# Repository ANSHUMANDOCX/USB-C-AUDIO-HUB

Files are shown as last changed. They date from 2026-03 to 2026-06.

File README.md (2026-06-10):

# USB C AUDIO + USB HUB

## About
This is a USB C HUB along with a Audio Out/In port. This design uses PCM2912A along with SL2.1A 

- It has 3 downstream USB-C ports and 1 USB-C input so we can connect any desired length of cable we want to use with it
- TRRS audio jack for headphones with integrated microphone along with a mute/unmute switch built into the hub 
## Usage guide
- using it is as simple as it can be you just need to plug into the single usb C on the side and connected it to your device there are no driver needed 
- It doesnt need any firmware flashing 
- Its compatible with windows and linux 
## Assembly guide
All you need to do is place the PCB at the base plate align the holes and place the Body on top of it and screw the two parts using M2.5x6 or M2.5x8 countersunk screws.
## Parts used 
- TRRS Audio port
- USB C ports 
- PCM2912A
- SL2.1A
## Features
- USB 2.0 Full-Speed audio interface
- Stereo DAC output for headphones
- Microphone input with bias supply
- Integrated USB hub for multiple downstream devices
## PCB SCHEMATIC AND CAD





## Build 
WhatsApp Image 2026-06-11 at 12 53 12 AM
WhatsApp Image 2026-06-11 at 12 53 12 AM (1)
WhatsApp Image 2026-06-11 at 12 53 12 AM (2)
WhatsApp Image 2026-06-11 at 12 53 10 AM (1)
WhatsApp Image 2026-06-11 at 12 53 11 AM
https://drive.google.com/file/d/1LVbVrCVM0A2IdHVQDUf04vvttPNs0SB3/view?usp=sharing

## BOM
| SL NO | DESCRIPTION | SUPPLIER | PRICE |
|---|---|---|---|
| 1 | [LCSC BOM items](https://github.com/ANSHUMANDOCX/USB-C-AUDIO-HUB/blob/main/PCB/BOM.csv) | LCSC | $22 |
| 2 | PCB and Stencil | JLCPCB | $16 |
| 3 | Screws and Heatset Inserts | Only Screws | $2 |
|4| [Solder Paste](https://www.flipkart.com/babatools-rl-403-solder-paste-10cc-1-w-simple/p/itm13022305a7dd0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,1,G,11214002,g,search,,784823478926,,,,c,,,,,,,&&cmpid=content_23274603117_gmc_pla&gad_campaignid=23274603117) | Flipkart| 4$|
|  | **TOTAL** |  | **$44** |

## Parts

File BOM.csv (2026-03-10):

Index | LCSC# | MPN | Manufacturer | Package | Customer # | Description | RoHS | Quantity | MOQ | Multiple | Unit Price($) | Extended Price($) | Product Link
1 | C60474 | CC0402KRX7R7BB104 | YAGEO | 0402 |  | 100nF ±10% 16V Ceramic Capacitor X7R 0402 | yes | 100 | 100 | 100 | 0.0010 | 0.10 | https://www.lcsc.com/product-detail/C60474.html
2 | C192893 | SL2.1A | CoreChips | SOP-16 |  | 4 USB 2.0 Hub SOP-16 Interface Controllers RoHS | yes | 5 | 5 | 5 | 0.2329 | 1.16 | https://www.lcsc.com/product-detail/C192893.html
3 | C475497 | PCM2912APJTR | TI | TQFP-32(7x7) |  | Encoder/decoder USB TQFP-32(7x7) CODECS RoHS | yes | 2 | 1 | 1 | 4.6145 | 9.23 | https://www.lcsc.com/product-detail/C475497.html
4 | C318866 | XKB5858-Z-80 | XKB Connection | DIP-6,5.8x5.8mm |  | Latching DPDT Through Hole Square Button 1.6N 30V DIP-6,5.8x5.8mm Pushbutton Switches RoHS | yes | 5 | 5 | 5 | 0.1721 | 0.86 | https://www.lcsc.com/product-detail/C318866.html
5 | C60490 | RC0402FR-0710KL | YAGEO | 0402 |  | 62.5mW 10kΩ 50V Thick Film Resistor ±100ppm/℃ ±1% 0402 Chip Resistor - Surface Mount RoHS | yes | 100 | 100 | 100 | 0.0008 | 0.08 | https://www.lcsc.com/product-detail/C60490.html
6 | C114759 | RC0402FR-071K5L | YAGEO | 0402 |  | 62.5mW 1.5kΩ 50V Thick Film Resistor ±100ppm/℃ ±1% 0402 Chip Resistor - Surface Mount RoHS | yes | 100 | 100 | 100 | 0.0008 | 0.08 | https://www.lcsc.com/product-detail/C114759.html
7 | C17477 | 0805W8F0000T5E | UNI-ROYAL | 0805 |  | 0Ω ±1% 125mW 0805 Thick Film Resistor | yes | 100 | 100 | 100 | 0.0021 | 0.21 | https://www.lcsc.com/product-detail/C17477.html
8 | C105872 | RC0402FR-075K1L | YAGEO | 0402 |  | 5.1kΩ 62.5mW 50V Thick Film Resistor ±100ppm/℃ ±1% 0402 Chip Resistor - Surface Mount RoHS | yes | 100 | 100 | 100 | 0.0009 | 0.09 | https://www.lcsc.com/product-detail/C105872.html
9 | C137933 | RC0402FR-07820RL | YAGEO | 0402 |  | 820Ω 62.5mW 50V Thick Film Resistor ±100ppm/℃ ±1% 0402 Chip Resistor - Surface Mount RoHS | yes | 100 | 100 | 100 | 0.0008 | 0.08 | https://www.lcsc.com/product-detail/C137933.html
10 | C114765 | RC0402FR-0722RL | YAGEO | 0402 |  | 22Ω 62.5mW 50V Thick Film Resistor ±100ppm/℃ ±1% 0402 Chip Resistor - Surface Mount RoHS | yes | 100 | 100 | 100 | 0.0008 | 0.08 | https://www.lcsc.com/product-detail/C114765.html
11 | C16772 | CL05B224KO5NNNC | Samsung Electro-Mechanics | 0402 |  | 220nF ±10% 16V Ceramic Capacitor X7R 0402 | yes | 50 | 50 | 50 | 0.0041 | 0.21 | https://www.lcsc.com/product-detail/C16772.html
12 | C106200 | CC0402JRNPO9BN101 | YAGEO | 0402 |  | 100pF ±5% 50V Ceramic Capacitor NP0 0402 | yes | 100 | 100 | 100 | 0.0012 | 0.12 | https://www.lcsc.com/product-detail/C106200.html
13 | C107000 | CC0402JRNPO9BN200 | YAGEO | 0402 |  | 20pF ±5% 50V Ceramic Capacitor NP0 0402 | yes | 100 | 100 | 100 | 0.0011 | 0.11 | https://www.lcsc.com/product-detail/C107000.html
14 | C7196 | TAJB107M010RNJ | Kyocera AVX | CASE-B-3528-21(mm) |  | 100uF ±20% 10V Tantalum Capacitors 1.4Ω@100kHz CASE-B-3528-21(mm) | yes | 3 | 1 | 1 | 0.3492 | 1.05 | https://www.lcsc.com/product-detail/C7196.html
15 | C7469983 | FVH010ADA101M0554 | FOSAN | 5x5.4 |  | 100uF ±20% 10V Aluminum Electrolytic Capacitors | yes | 20 | 20 | 20 | 0.0341 | 0.68 | https://www.lcsc.com/product-detail/C7469983.html
16 | C315248 | CL05A106MP5NUNC | Samsung Electro-Mechanics | 0402 |  | 10uF ±20% 10V Ceramic Capacitor X5R 0402 | yes | 20 | 20 | 20 | 0.0091 | 0.18 | https://www.lcsc.com/product-detail/C315248.html
17 | C51412 | CL10A335KP8NNNC | Samsung Electro-Mechanics | 0603 |  | 3.3uF ±10% 10V Ceramic Capacitor X5R 0603 | yes | 10 | 10 | 10 | 0.0193 | 0.19 | https://www.lcsc.com/product-detail/C51412.html
18 | C14445 | CL05A105KP5NNNC | Samsung Electro-Mechanics | 0402 |  | 1uF ±10% 10V Ceramic Capacitor X5R 0402 | yes | 100 | 100 | 100 | 0.0021 | 0.21 | https://www.lcsc.com/product-detail/C14445.html
19 | C18185602 | PJ-320A-4P DIP | SHOU HAN | Through Hole |  | 3.5mm Headphone Jack 0.5A 30V Through Hole | yes | 10 | 10 | 10 | 0.0518 | 0.52 | https://www.lcsc.com/product-detail/C18185602.html
20 | C7528811 | H6OEL89CSC-SUGYLC-6M | YXC Crystal Oscillators | HC-49S-SMD |  | Crystal 6MHz ±20ppm 20pF HC-49S-SMD | yes | 5 | 5 | 5 | 0.0850 | 0.43 | https://www.lcsc.com/product-detail/C7528811.html
21 | C22400405 | FTC252012S1R0MBCD | cjiang | 1008 |  | 5.2A 1uH 16mΩ 6.5A ±20% 1008 Fixed Inductors RoHS | yes | 5 | 5 | 5 | 0.1119 | 0.56 | https://www.lcsc.com/product-detail/C22400405.html
22 | C105621 | CC0603JRNPO9BN200 | YAGEO | 0603 |  | 20pF ±5% 50V Ceramic Capacitor NP0 0603 | yes | 100 | 100 | 100 | 0.0027 | 0.27 | https://www.lcsc.com/product-detail/C105621.html
23 | C970683 | RVT1A101M0505 100UF 10V | DMBJ | SMD,D5xL5.4mm |  | 100uF ±20% 10V Aluminum Electrolytic Capacitors 2800hrs@105℃ | yes | 20 | 20 | 20 | 0.0354 | 0.71 | https://www.lcsc.com/product-detail/C970683.html
24 | C2927038 | USB-TYPE-C-018 | DEALON | SMD |  | USB-C (USB TYPE-C) Receptacle Connector 16 Position Surface Mount, Right Angle | yes | 10 | 10 | 10 | 0.0522 | 0.52 | https://www.lcsc.com/product-detail/C2927038.html
25 | C76960 | GRM1555C1H220JA01D | muRata | 0402 |  | 22pF ±5% 50V Ceramic Capacitor C0G 0402 | yes | 100 | 100 | 100 | 0.0026 | 0.26 | https://www.lcsc.com/product-detail/C76960.html

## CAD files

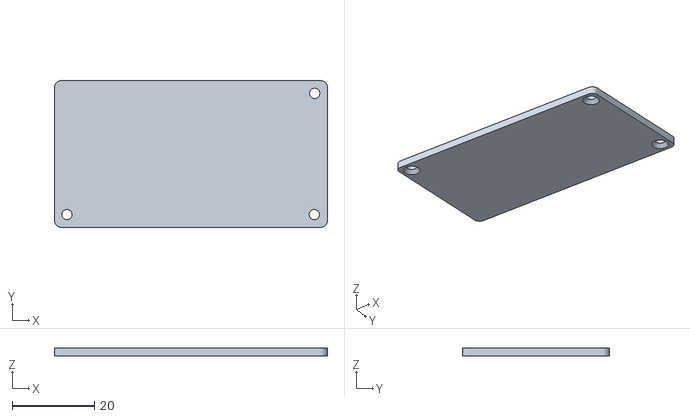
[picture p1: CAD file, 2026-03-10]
CAD/Base.stl
66.2 x 35.6 x 2.00

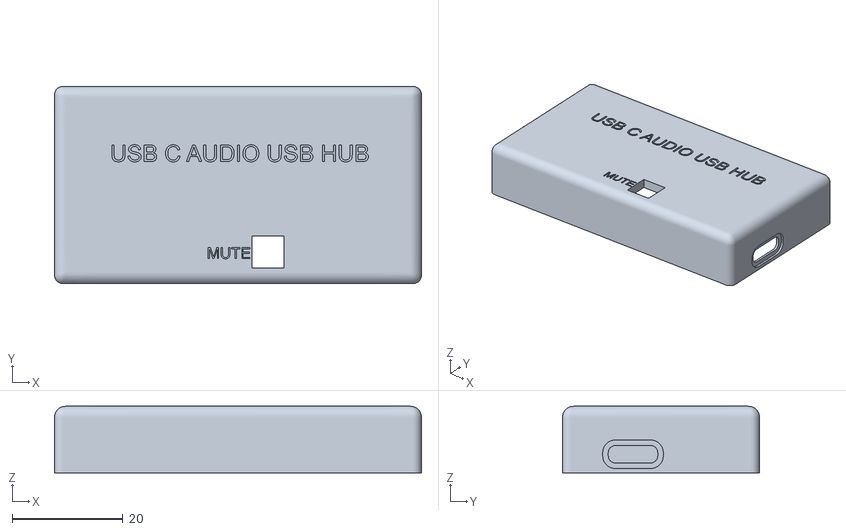
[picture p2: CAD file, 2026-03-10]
CAD/body.stl
66.2 x 35.6 x 12.0

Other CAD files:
CAD/Base.f3z
CAD/body.f3z

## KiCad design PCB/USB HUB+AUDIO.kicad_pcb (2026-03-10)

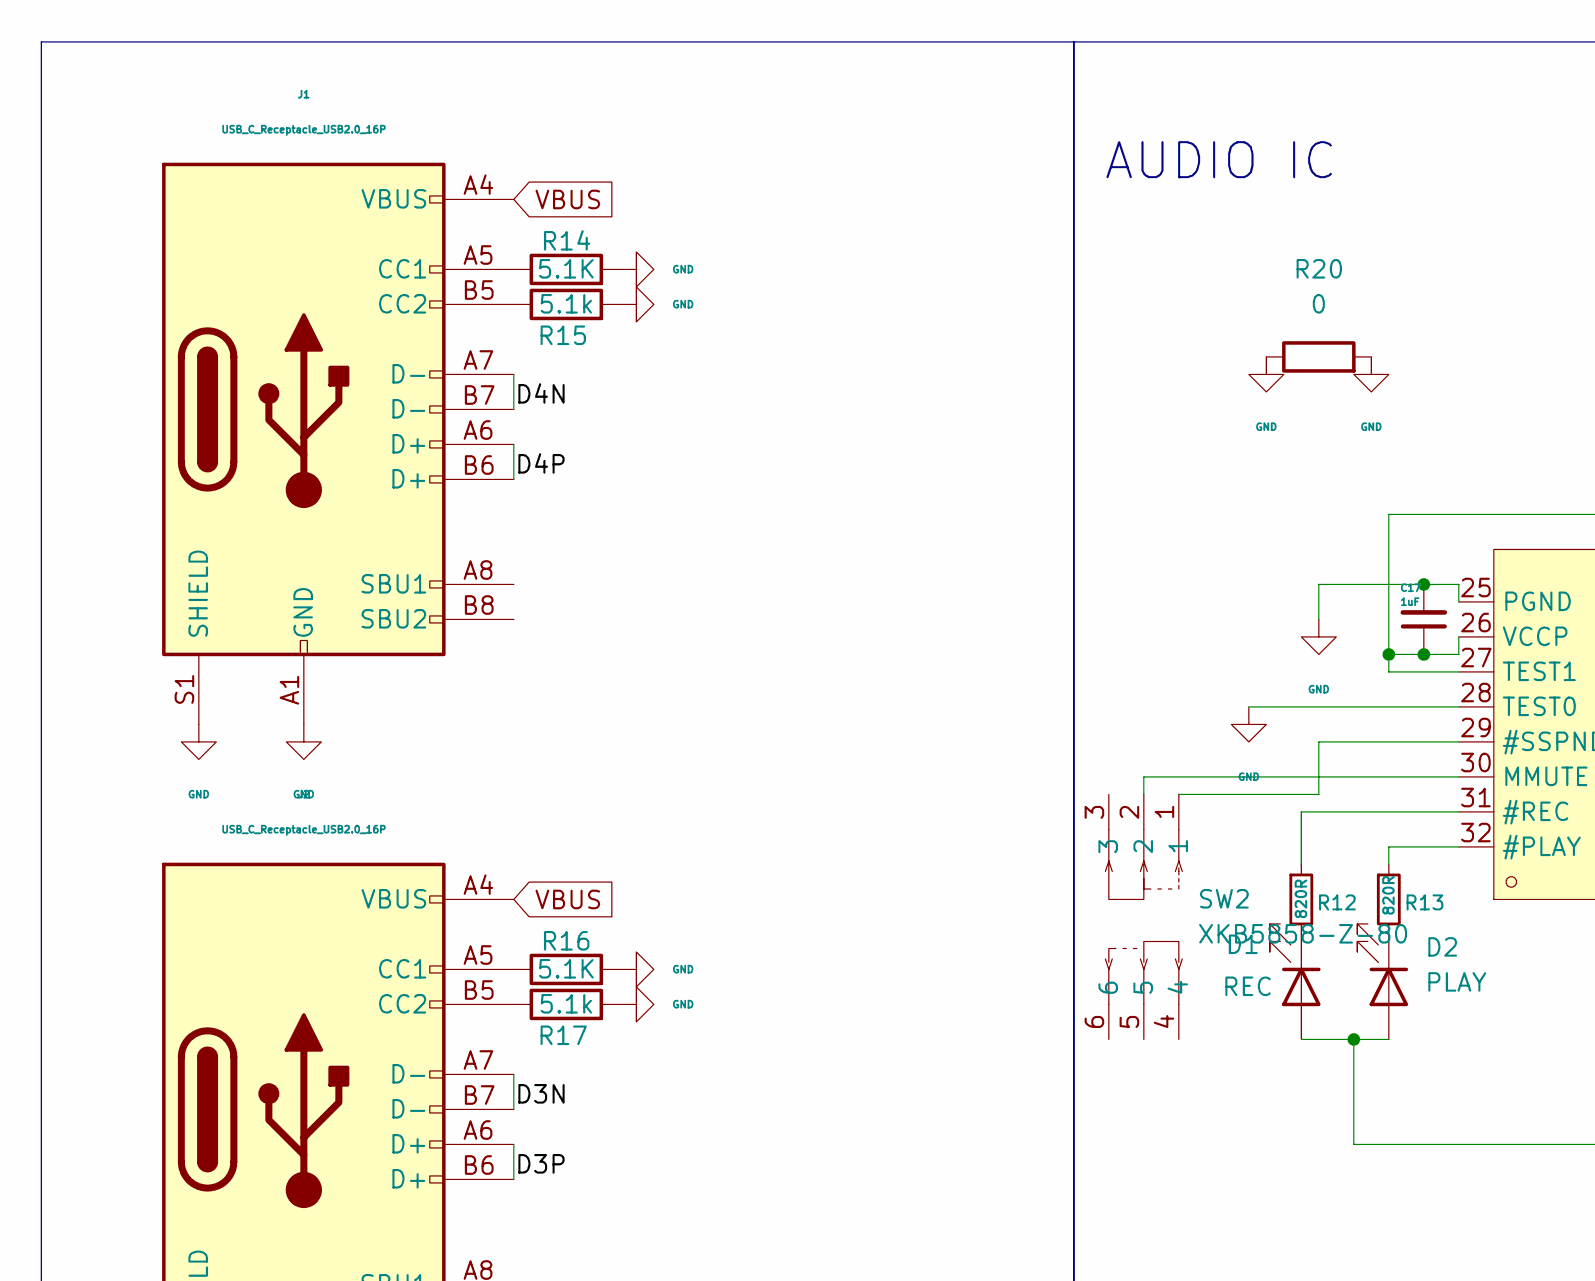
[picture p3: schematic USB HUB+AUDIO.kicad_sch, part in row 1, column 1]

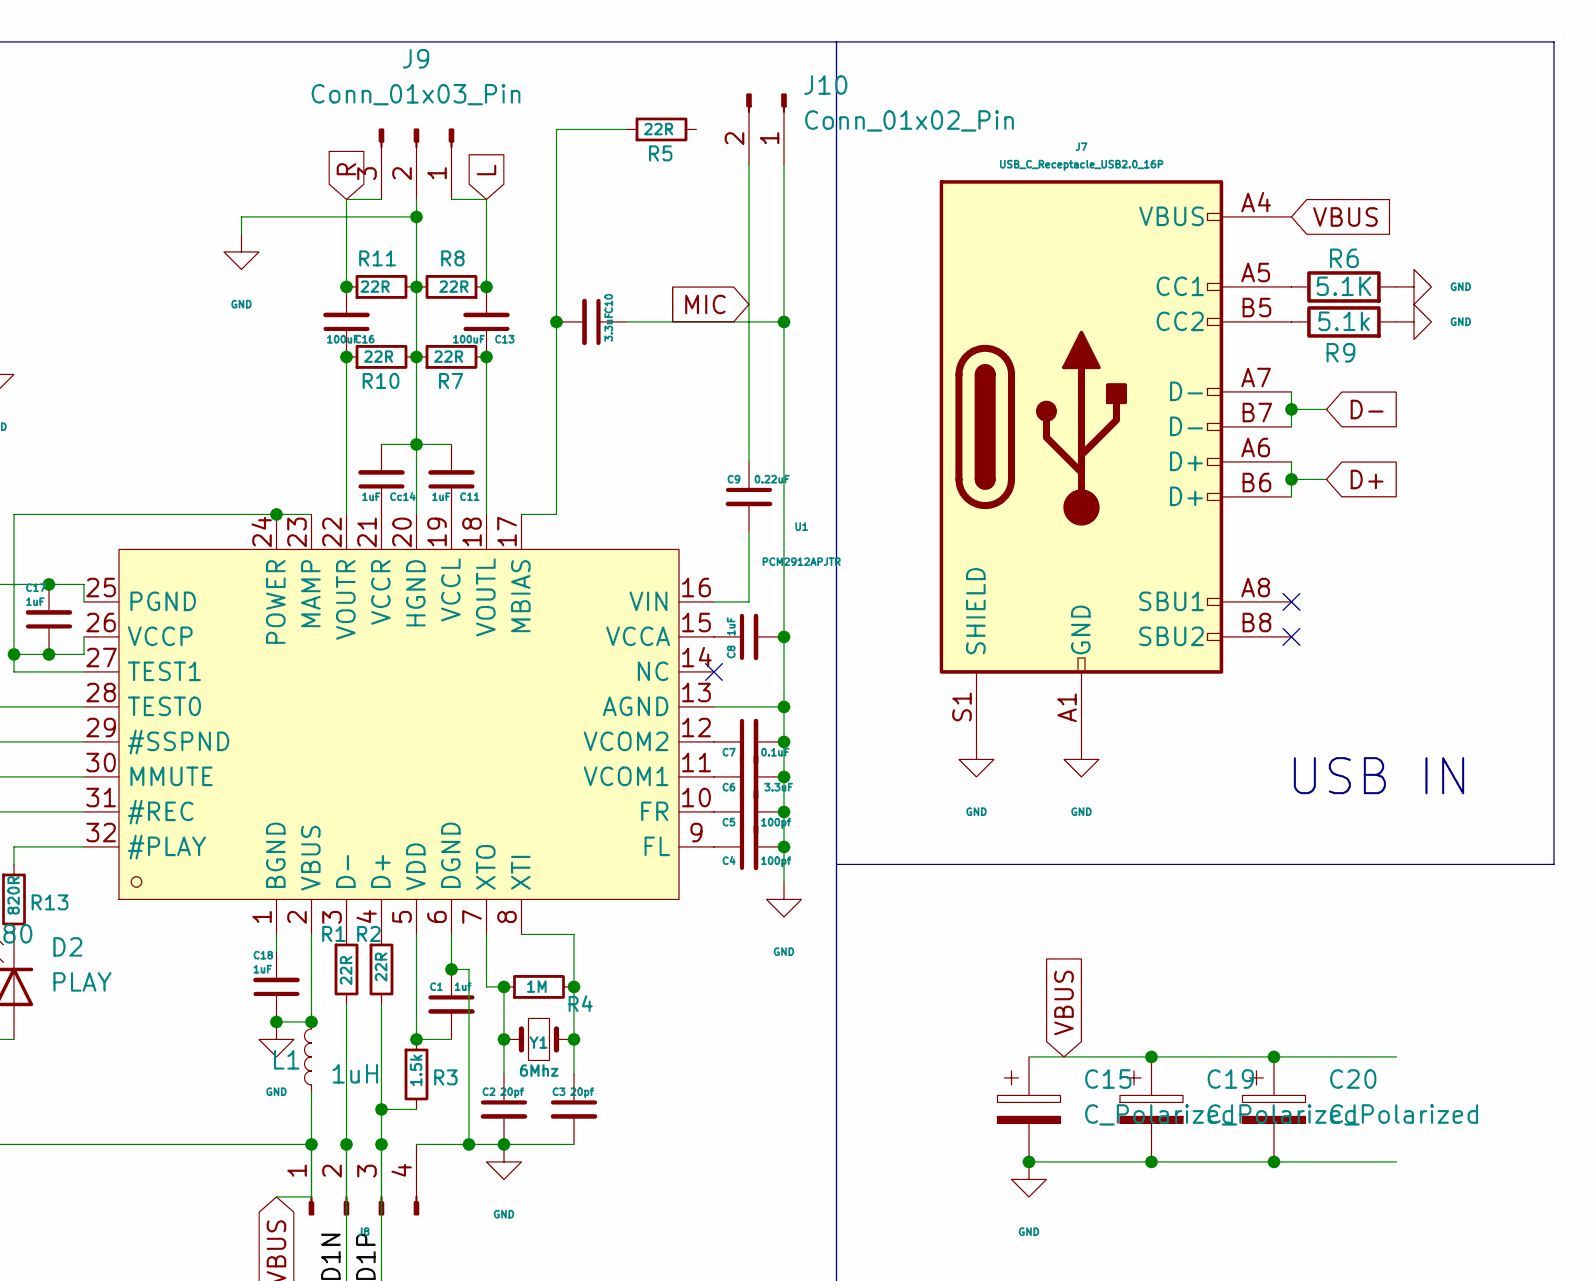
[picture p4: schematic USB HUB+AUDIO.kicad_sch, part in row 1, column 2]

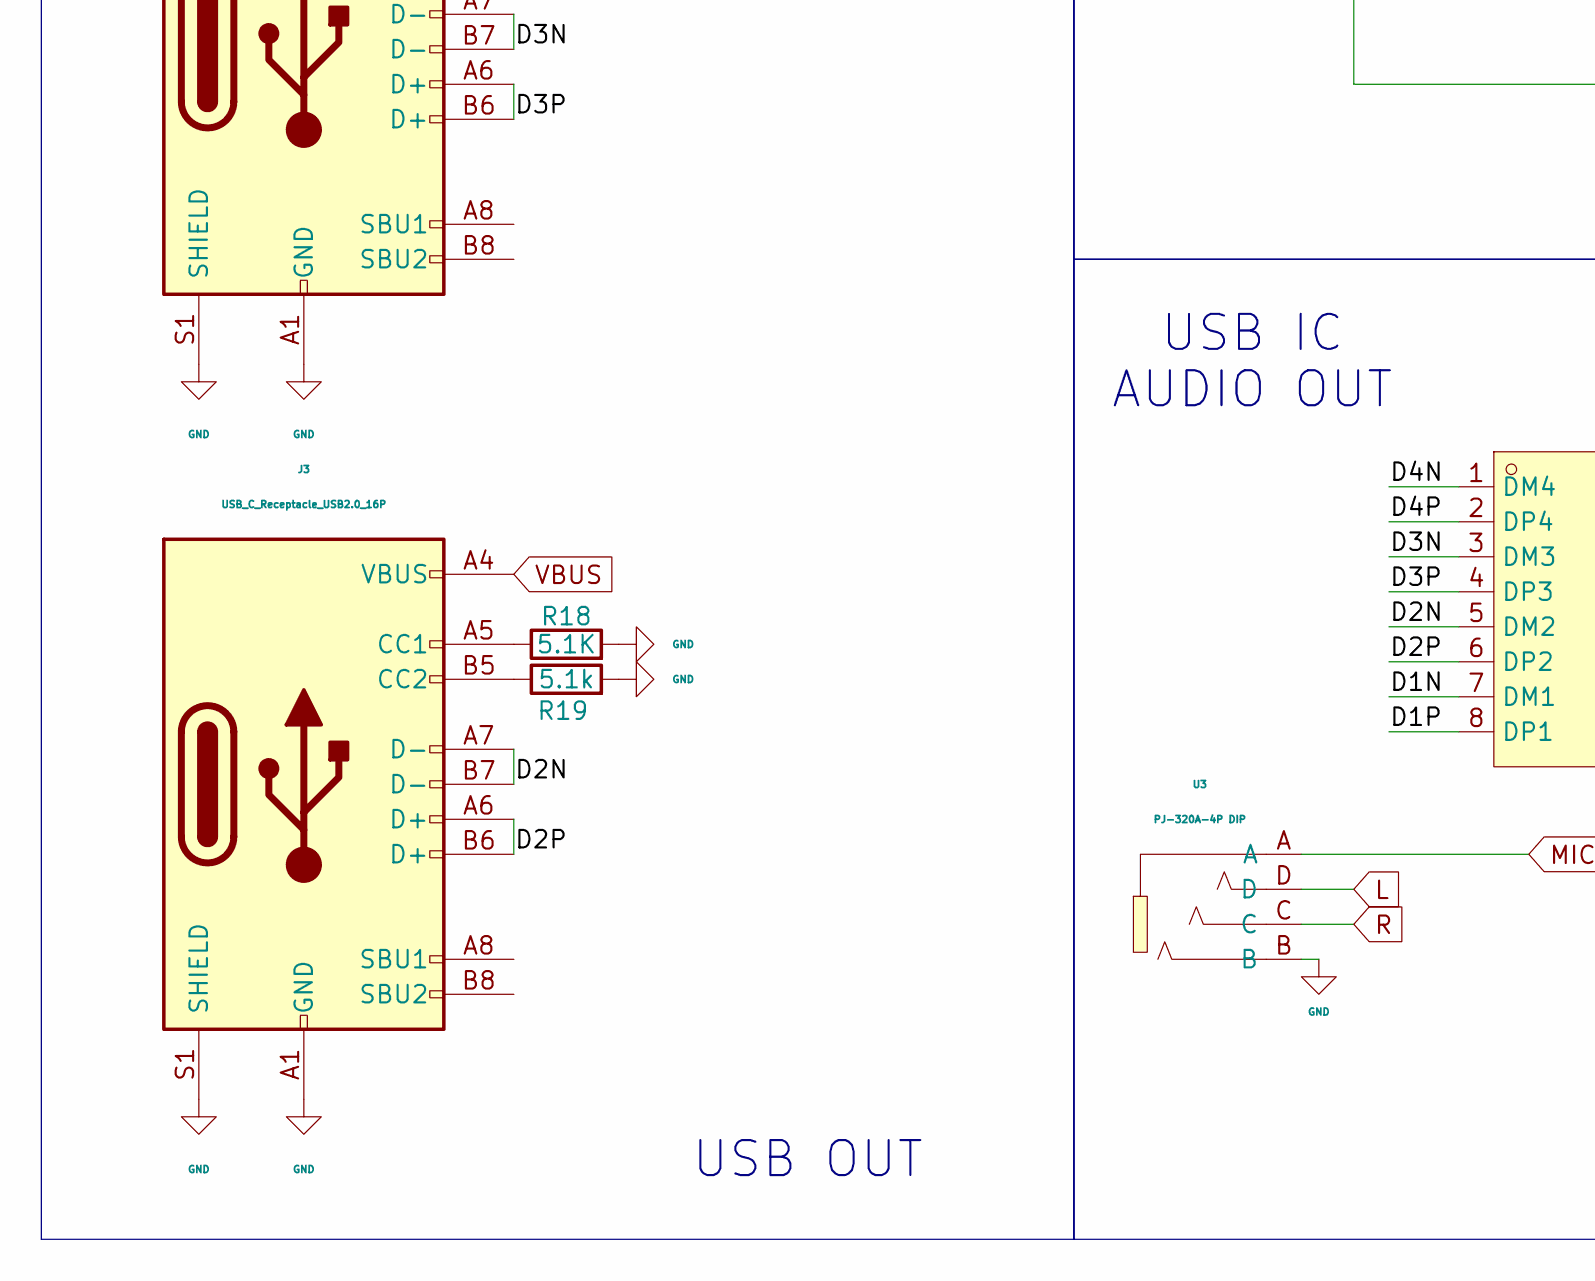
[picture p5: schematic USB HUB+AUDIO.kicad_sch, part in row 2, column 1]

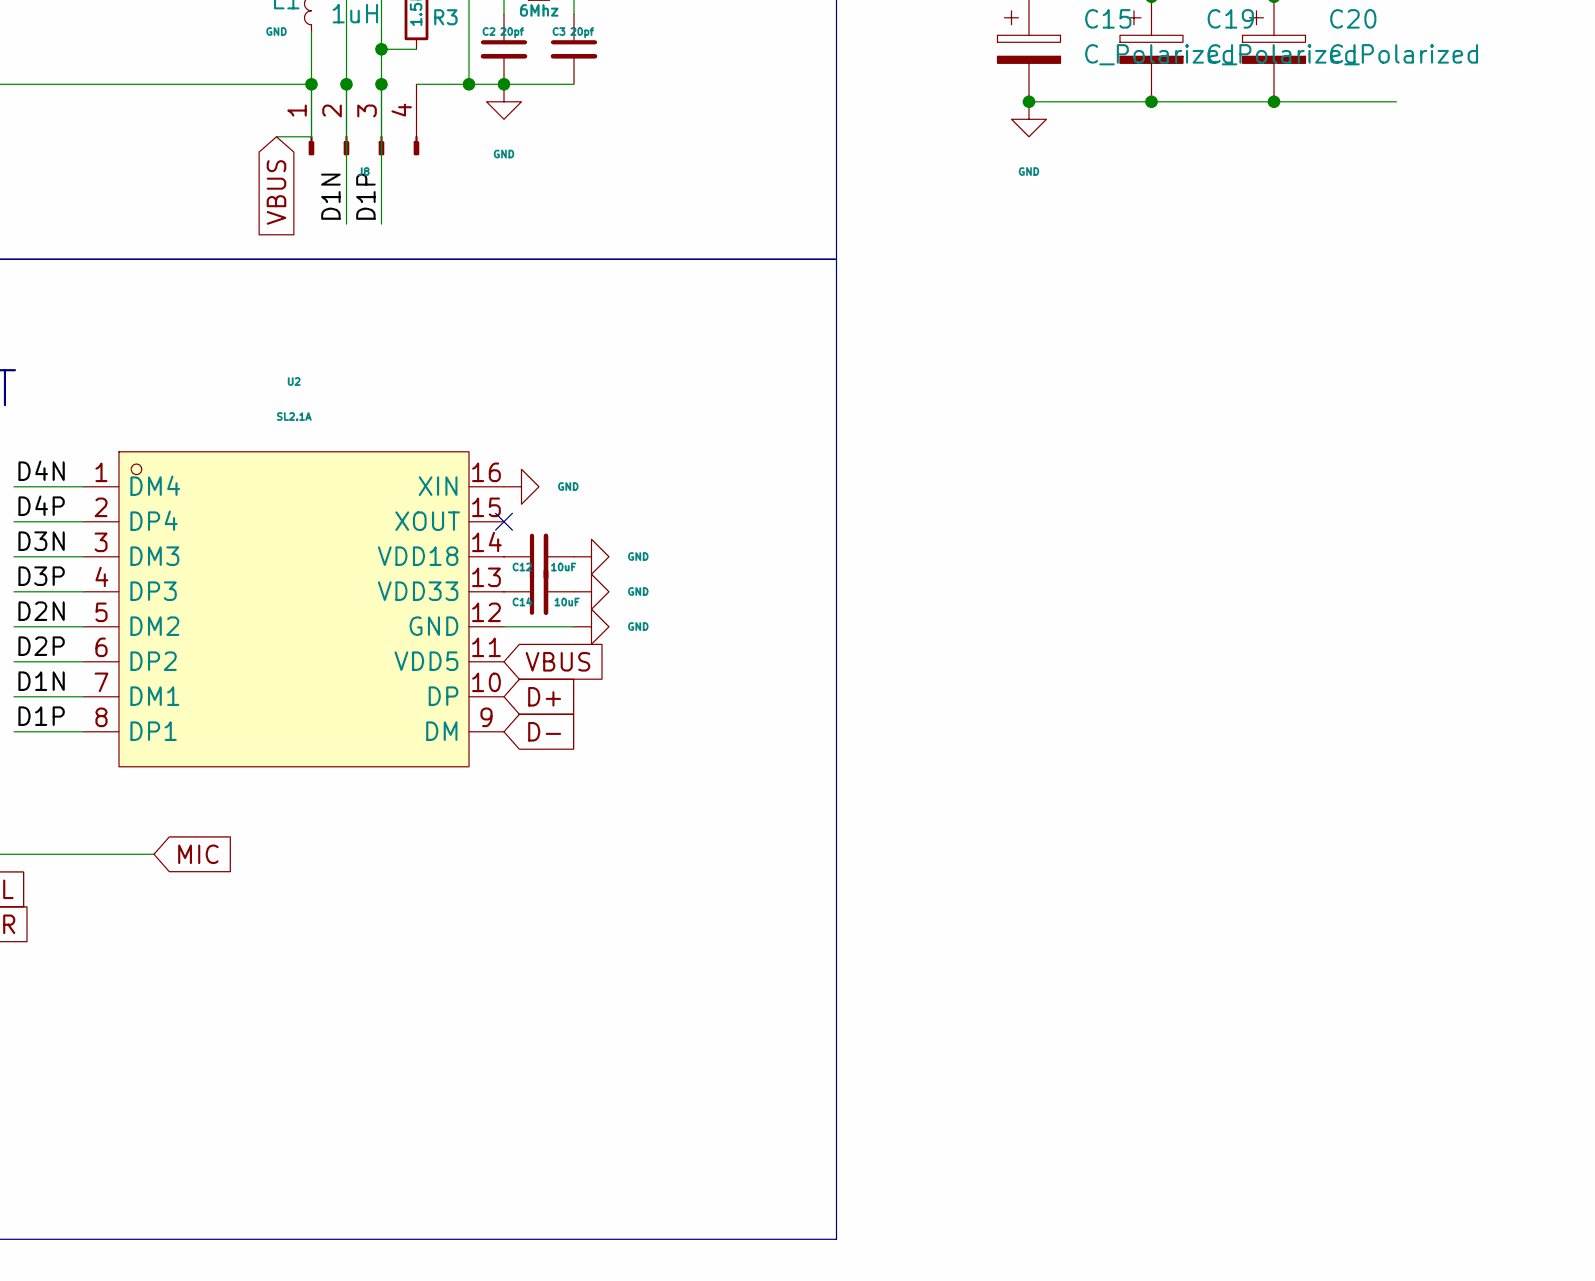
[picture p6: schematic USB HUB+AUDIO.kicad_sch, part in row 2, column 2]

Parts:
C1: 1uf; C_0402_1005Metric_Pad0.74x0.62mm_HandSolder
C2, C3: 20pf; C_0402_1005Metric_Pad0.74x0.62mm_HandSolder
C4, C5: 100pf; C_0402_1005Metric_Pad0.74x0.62mm_HandSolder
C6, C10: 3.3uF; C_0402_1005Metric_Pad0.74x0.62mm_HandSolder
C7: 0.1uF; C_0402_1005Metric_Pad0.74x0.62mm_HandSolder
C8, C11, C17, C18: 1uF; C_0402_1005Metric_Pad0.74x0.62mm_HandSolder
C9: 0.22uF; C_0402_1005Metric_Pad0.74x0.62mm_HandSolder
C12, C14: 10uF; C_0402_1005Metric_Pad0.74x0.62mm_HandSolder
C13, C16: 100uF; CP_Elec_5x5.4
C15, C19, C20: C_Polarized; CP_EIA-3528-15_AVX-H
Cc14: 1uF; C_0402_1005Metric_Pad0.74x0.62mm_HandSolder
D1: REC; LED_0603_1608Metric
D2: PLAY; LED_0603_1608Metric
J1, J2, J3, J7: USB_C_Receptacle_USB2.0_16P; USB_C_Receptacle_GCT_USB4105-xx-A_16P_TopMnt_Horizontal
J8: Conn_01x04_Pin; PinHeader_1x04_P2.54mm_Vertical
J9: Conn_01x03_Pin; PinHeader_1x03_P2.54mm_Vertical
J10: Conn_01x02_Pin; PinHeader_1x02_P2.54mm_Vertical
L1: 1uH; L1008
R1, R2, R5, R7, R8, R10, R11: 22R; R_0402_1005Metric
R3: 1.5k; R_0402_1005Metric
R4: 1M; R_0402_1005Metric
R6, R14, R16, R18: 5.1K; R_0402_1005Metric
R9, R15, R17, R19: 5.1k; R_0402_1005Metric
R12, R13: 820R; R_0402_1005Metric
R20: 0; R_0805_2012Metric
SW2: XKB5858-Z-80; SW-TH_XKB5858-Z-80; LCSC Part C318866
U1: PCM2912APJTR; TQFP-32_L7.0-W7.0-P0.80-LS9.0-TL; LCSC Part C475497
U2: SL2.1A; SOP-16_L10.0-W3.9-P1.27-LS6.0-BL; LCSC Part C192893
U3: PJ-320A-4P DIP; AUDIO-TH_PJ-320A-4P-DIP; LCSC Part C18185602
Y1: 6Mhz; CRYSTAL-SMD_L7.0-W4.0-LS7.8

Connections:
/D1N: J8.2, R1.2, U2.7 (DM1)
/D1P: J8.3, R2.2, R3.2, U2.8 (DP1)
/D2N: J3.A7 (D-), J3.B7 (D-), U2.5 (DM2)
/D2P: J3.A6 (D+), J3.B6 (D+), U2.6 (DP2)
/D3N: J2.A7 (D-), J2.B7 (D-), U2.3 (DM3)
/D3P: J2.A6 (D+), J2.B6 (D+), U2.4 (DP3)
/D4N: J1.A7 (D-), J1.B7 (D-), U2.1 (DM4)
/D4P: J1.A6 (D+), J1.B6 (D+), U2.2 (DP4)
D+: J7.A6 (D+), J7.B6 (D+), U2.10 (DP)
D-: J7.A7 (D-), J7.B7 (D-), U2.9 (DM)
GND: C1.1, C2.2, C3.2, C4.2, C5.2, C6.2, C7.2, C8.2, C10.1, C11.2, C12.2, C14.2, C15.2, C17.2, C18.1, C19.2, C20.2, Cc14.2, J1.A1 (GND), J1.A12 (GND), J1.B1 (GND), J1.B12 (GND), J1.S1 (SHIELD), J2.A1 (GND), J2.A12 (GND), J2.B1 (GND), J2.B12 (GND), J2.S1 (SHIELD), J3.A1 (GND), J3.A12 (GND), J3.B1 (GND), J3.B12 (GND), J3.S1 (SHIELD), J7.A1 (GND), J7.A12 (GND), J7.B1 (GND), J7.B12 (GND), J7.S1 (SHIELD), J8.4, J9.2, J10.1, L1.2, R6.2, R7.1, R8.2, R9.2, R10.2, R11.2, R14.2, R15.2, R16.2, R17.2, R18.2, R19.2, R20.1, R20.2, U1.2 (VBUS), U1.6 (DGND), U1.13 (AGND), U1.20 (HGND), U1.25 (PGND), U1.28 (TEST0), U2.12 (GND), U2.16 (XIN), U3.B
L: C13.2, J9.1, R8.1, U3.D
MIC: C9.1, J10.2, U3.A
unnamed: D1.1 (K), R12.2
unnamed: D2.1 (K), R13.2
unnamed: J1.A5 (CC1), R14.1
unnamed: J1.B5 (CC2), R15.1
unnamed: J2.A5 (CC1), R16.1
unnamed: J2.B5 (CC2), R17.1
unnamed: J3.A5 (CC1), R18.1
unnamed: J3.B5 (CC2), R19.1
unnamed: J7.A5 (CC1), R6.1
unnamed: J7.B5 (CC2), R9.1
unnamed: R13.1, U1.32 (#PLAY)
unnamed: R12.1, U1.31 (#REC)
unnamed: SW2.1, U1.29 (#SSPND)
unnamed: C18.2, U1.1 (BGND)
unnamed: R2.1, U1.4 (D+)
unnamed: R1.1, U1.3 (D-)
unnamed: C4.1, U1.9 (FL)
unnamed: C5.1, U1.10 (FR)
unnamed: C17.1, U1.23 (MAMP), U1.24 (POWER), U1.26 (VCCP), U1.27 (TEST1)
unnamed: C10.2, R5.1, U1.17 (MBIAS)
unnamed: SW2.2, U1.30 (MMUTE)
unnamed: C8.1, U1.15 (VCCA)
unnamed: C11.1, U1.19 (VCCL)
unnamed: Cc14.1, U1.21 (VCCR)
unnamed: C6.1, U1.11 (VCOM1)
unnamed: C7.1, U1.12 (VCOM2)
unnamed: C1.2, R3.1, U1.5 (VDD)
unnamed: C9.2, U1.16 (VIN)
unnamed: C13.1, R7.2, U1.18 (VOUTL)
unnamed: C16.1, R10.1, U1.22 (VOUTR)
unnamed: C3.1, R4.2, U1.8 (XTI), Y1.2
unnamed: C2.1, R4.1, U1.7 (XTO), Y1.1
unnamed: C12.1, U2.14 (VDD18)
unnamed: C14.1, U2.13 (VDD33)
R: C16.2, J9.3, R11.1, U3.C
VBUS: C15.1, C19.1, C20.1, D1.2 (A), D2.2 (A), J1.A4 (VBUS), J1.A9 (VBUS), J1.B4 (VBUS), J1.B9 (VBUS), J2.A4 (VBUS), J2.A9 (VBUS), J2.B4 (VBUS), J2.B9 (VBUS), J3.A4 (VBUS), J3.A9 (VBUS), J3.B4 (VBUS), J3.B9 (VBUS), J7.A4 (VBUS), J7.A9 (VBUS), J7.B4 (VBUS), J7.B9 (VBUS), J8.1, L1.1, U2.11 (VDD5)

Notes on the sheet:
AUDIO IC
USB OUT
USB IN
USB IC AUDIO OUT

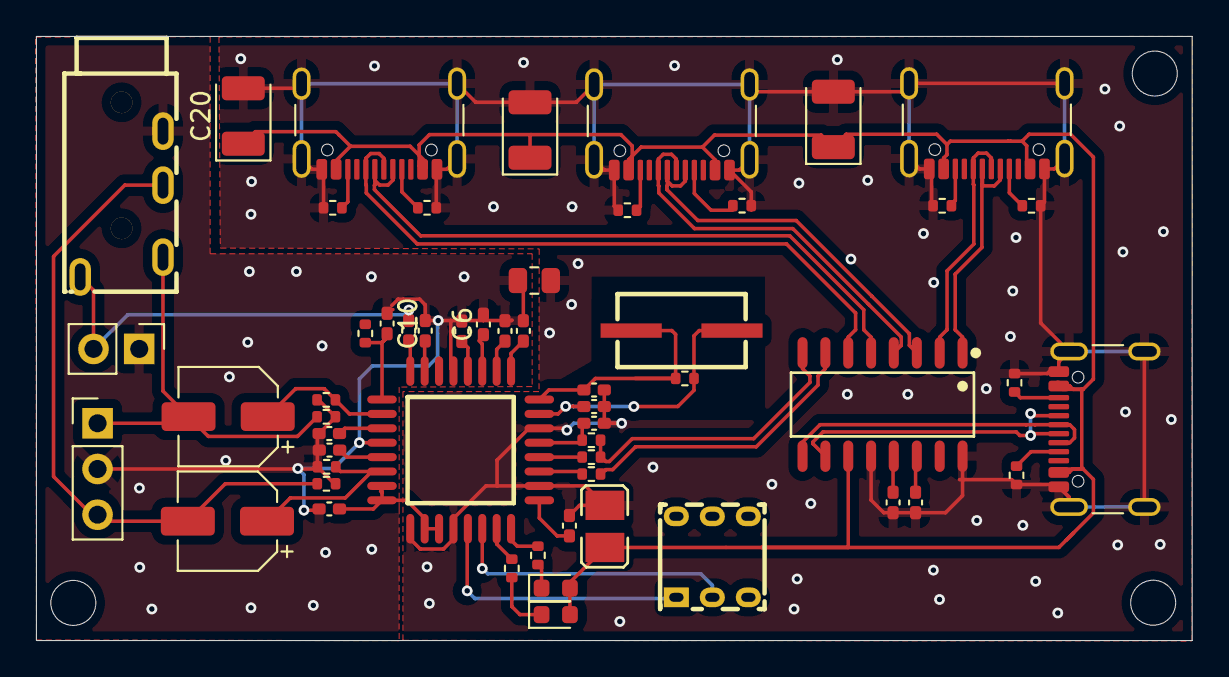
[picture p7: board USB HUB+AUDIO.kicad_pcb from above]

Board: 2 copper layers, 64.2 x 33.6 mm, 55 parts (0 on the bottom side), 49 nets.

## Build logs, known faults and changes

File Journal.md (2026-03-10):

<!--
  This journal is auto generated by Hack Club Blueprint.
-->

# 2/18/2026 - Researched for the parts  

_Time spent: 1.5h_  

For the USB hub i will be using the SL2.1A USB hub ic.

And for the USB DAC it was my first time working with it so i was confused as to which IC would be good to use and had to do quite a but if research before i found kind a the perfect one.

the ones i stumbled across were CM108B, PCM2704 and PCM2912A 
finally i went with [PCM2912a ](https://www.lcsc.com/product-detail/C475497.html) since it was both cheap as well had the option for MIC IN

so i will be making the hub based on these.



# 2/21/2026 - Completed the Audio Part  

_Time spent: 2.0h_  



Completed making the audio portion of the hub taking reference from the datasheet for PCM2912A

there will be 2 led indicator to indicate the functioning of the PLAY and REC option also there will be a mute switch 

# 2/22/2026 - Completed Schematic   

_Time spent: 1.5h_  

Completed routing the USB in and USB out 
i have added usb C as input and there will be dual option for extension either via USB C or USB A and at the input i will use USB C 

for the audio out also there will he 2 options 
single port for AUIDO+ MIC
DUAL port for AUIDO and MIC separately 



# 3/6/2026 3 PM - Routed the PCB  

_Time spent: 2.5h_  

completed routing the PCB and kept the AGND and PGND separate and connected the with a 0 ohm resistor at a single point to avoid unnecessary noise in headphone also, i removed the dual usb system since i didnt like it much along with the dual headphone input thing. 


# 3/6/2026 8 PM - did a few changes  

_Time spent: 1.0h_  

refined the copper pour 
changed the switch to a latchable one, 
removed the copper pour under the crystal to avoid parasitic capacitance to avoid noise 
did ground stitching 
assigned the 3d model of all the components 




# 3/7/2026 - Started out with the CAD  

_Time spent: 2.0h_  

started out withe cad it will be a two part design which when connected will hold the pcb too. 

also made the cut out for the type C connector this took some time to perfect eh dimensions.



# 3/9/2026 - Completed CAD  

_Time spent: 3.0h_  

- i have completed the cad for the PCB 
- added a 1mm depth near the USB and Audio ports for better spacing and aesthetics 
- I have also added chamfer at the bottom to screw m2.5mm screws so that it fits flush in
- the design is such that the top past will hold on the pcb like a clamp 
